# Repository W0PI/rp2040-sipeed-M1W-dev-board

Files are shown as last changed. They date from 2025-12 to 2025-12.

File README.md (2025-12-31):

# rp2040-sipeed-M1W-dev-board

*the names of the PCB files are different cause at the very start i sightly chnaged what i was doing and didnt know how to change kicad project names*

a rp2040 and a sippeed M1W on one board both connected by uart the M1W has a camera and lcd connector aswell as 8 mics in a circle for directional detection

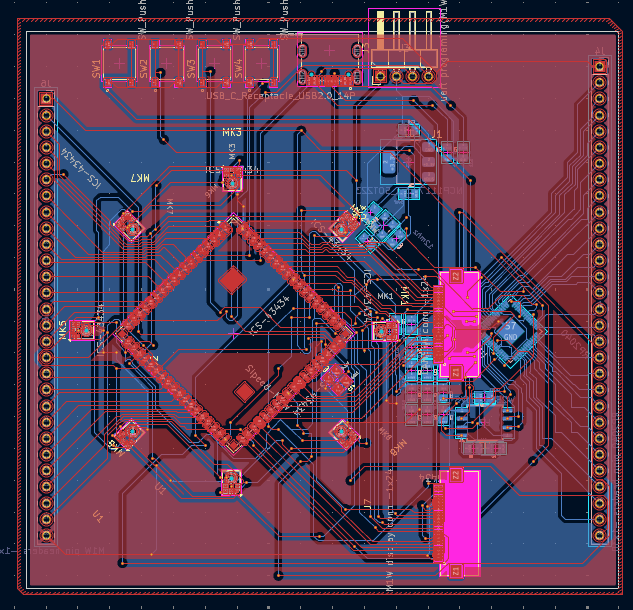
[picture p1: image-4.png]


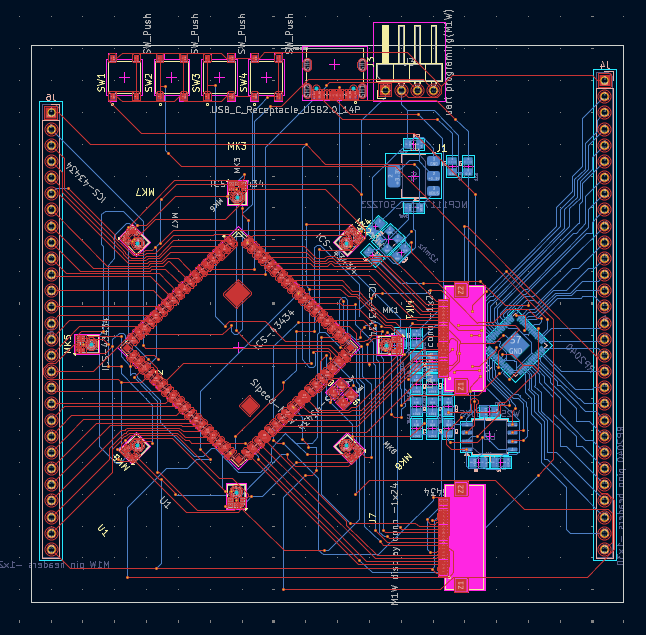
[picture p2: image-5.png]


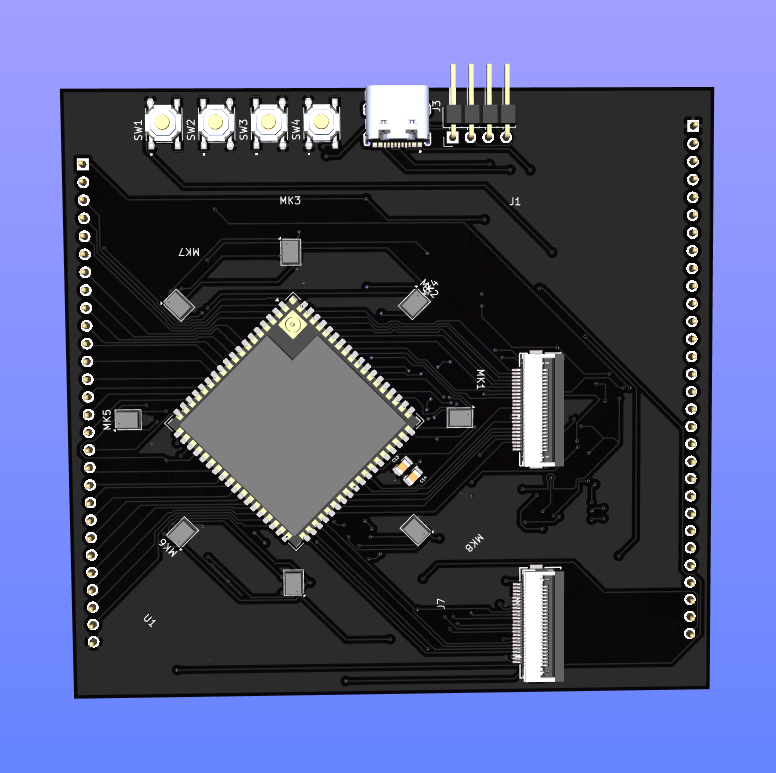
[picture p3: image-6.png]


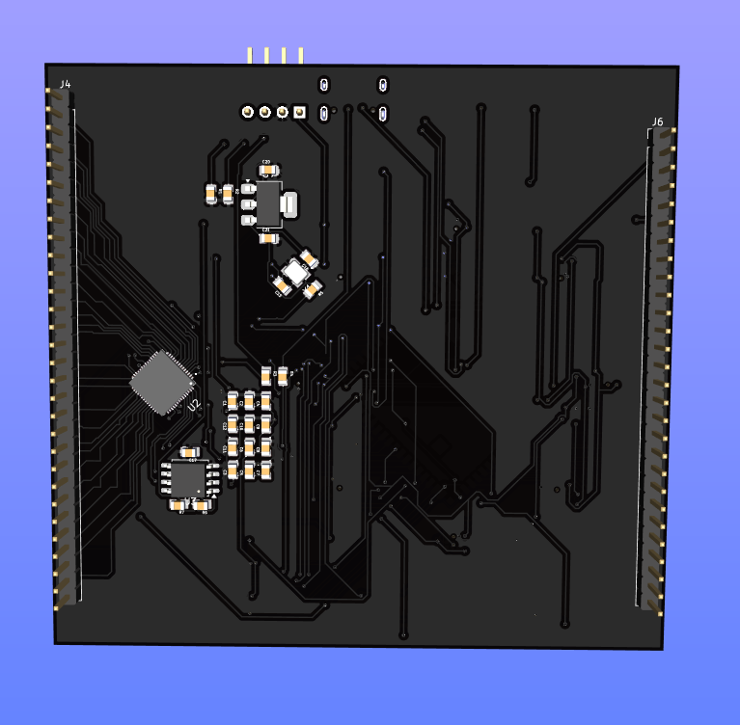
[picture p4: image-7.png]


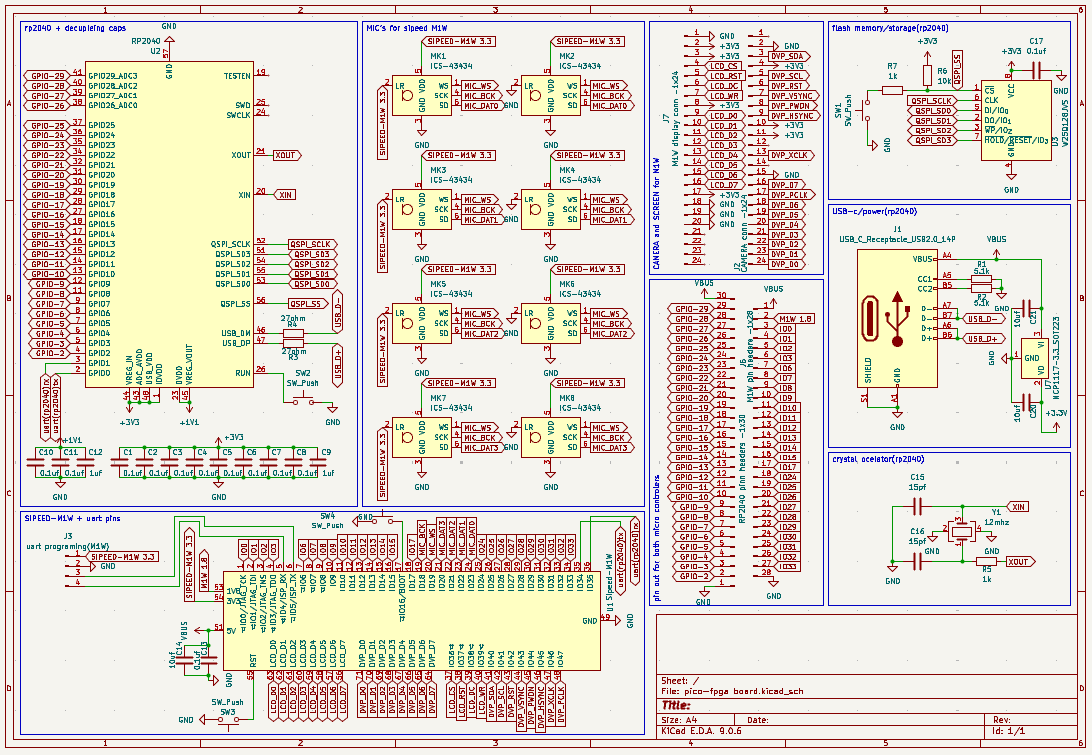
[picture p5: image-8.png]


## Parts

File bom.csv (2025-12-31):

Designator | Footprint | Quantity | Value | LCSC Part #
C1, C10, C11, C13, C17, C2, C3, C4, C5, C6, C7, C8 | 0805 | 12 | 0.1uf
C12, C9 | 0805 | 2 | 1uf
C14, C20, C21 | 0805 | 3 | 10uf
C15, C16 | 0805 | 2 | 15pf
J1 | USB-C | 1 | USB_C_Receptacle_USB2.0_14P
J2 | CAMERA conn | 1 | CAMERA conn -1x24
J3 | PinHeader_1x04_P2.54mm_Horizontal | 1 | uart programing(M1W)
J4 | PinHeader_1x30_P2.54mm_Vertical | 1 | RP2040 pinn headers -1x30
J6 | PinHeader_1x28_P2.54mm_Vertical | 1 | M1W pin headers -1x28
J7 | CAMERA conn | 1 | M1W display conn -1x24
MK1, MK2, MK3, MK4, MK5, MK6, MK7, MK8 | InvenSense_ICS-43434-6_3.5x2.65mm | 8 | ICS-43434
R1, R2 | 0805 | 2 | 5.1k
R3, R4 | 0805 | 2 | 27ohm
R5, R7 | 0805 | 2 | 1k
R6 | 0805 | 1 | 10k
SW1, SW2, SW3, SW4 | button | 4 | SW_Push
U1 | Sipeed-M1W | 1 | Sipeed-M1W
U2 | RP2040 | 1 | RP2040
U3 | SOIC-8_5.3x5.3mm_P1.27mm | 1 | W25Q128JVS
U7 | SOT-223-3_TabPin2 | 1 | NCP1117-3.3_SOT223
Y1 | 12mhz crystal | 1 | 12mhz

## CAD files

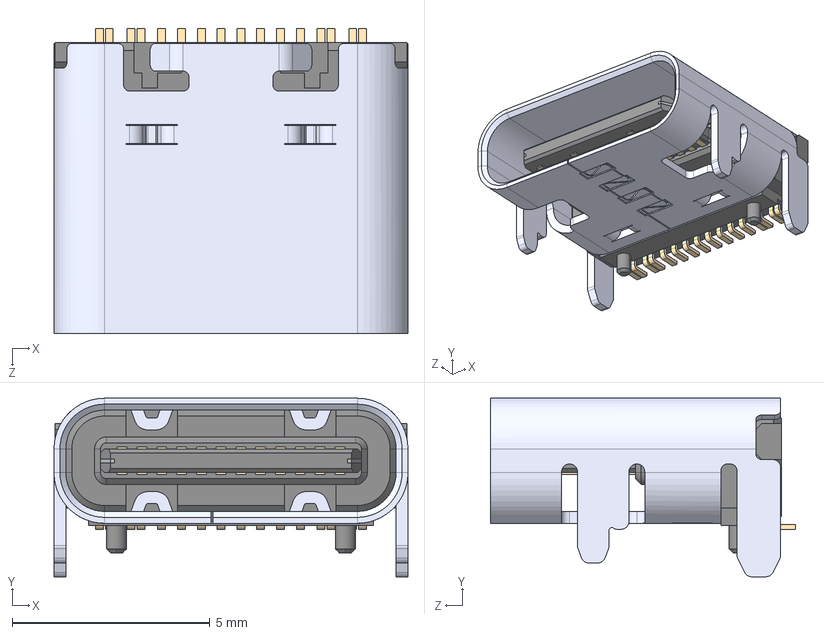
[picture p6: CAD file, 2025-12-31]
KICAD PCB files/extra 3d models/USB-C.STEP
8.94 x 4.51 x 7.71 mm

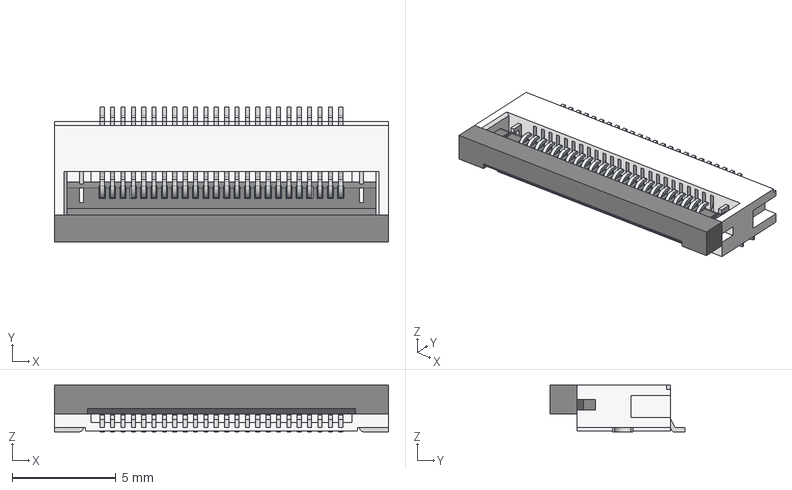
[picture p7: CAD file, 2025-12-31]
KICAD PCB files/extra 3d models/CAMERA conn.step
16.1 x 6.50 x 2.25 mm
6871xx149022_Pin x 24
6871xx149022_Patte
6871xx149022_Patte2
687124149022_Actuator

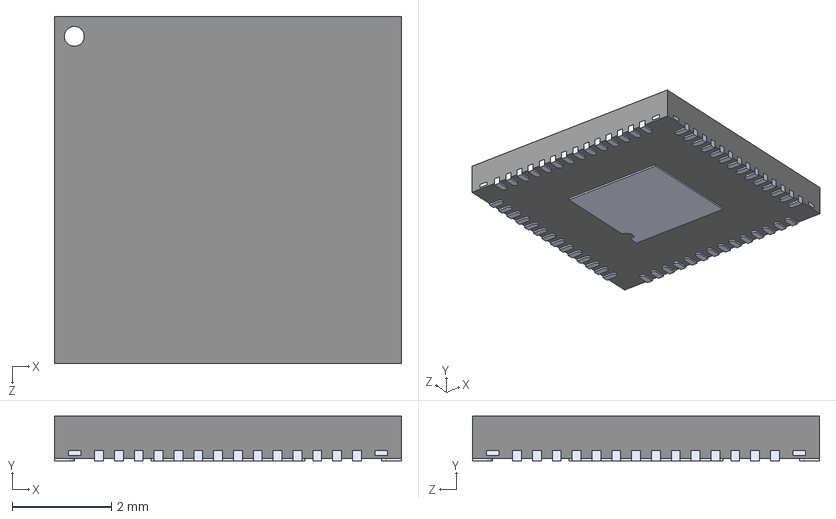
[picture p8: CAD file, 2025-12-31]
KICAD PCB files/extra 3d models/RP2040.step
7.00 x 0.9 x 7.00 mm

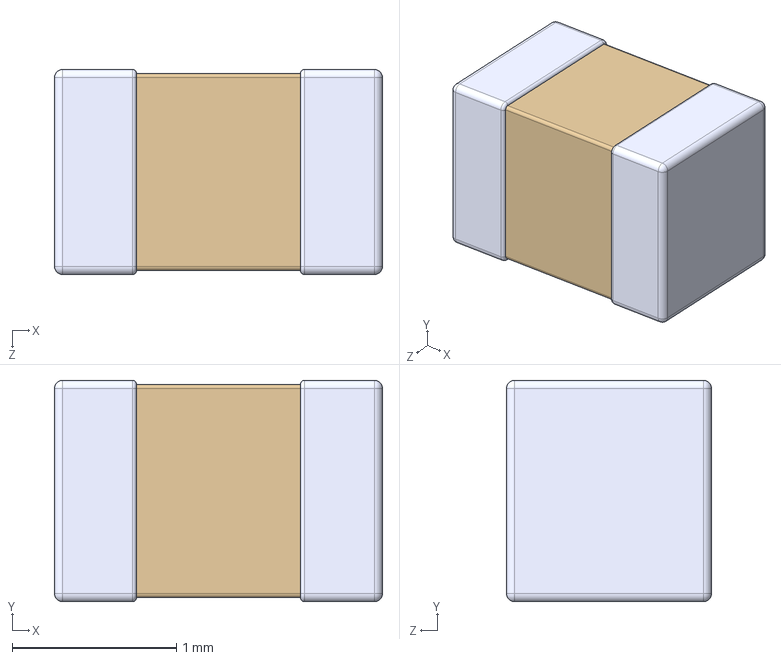
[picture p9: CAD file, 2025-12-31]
KICAD PCB files/extra 3d models/0805.step
2.00 x 1.35 x 1.25 mm

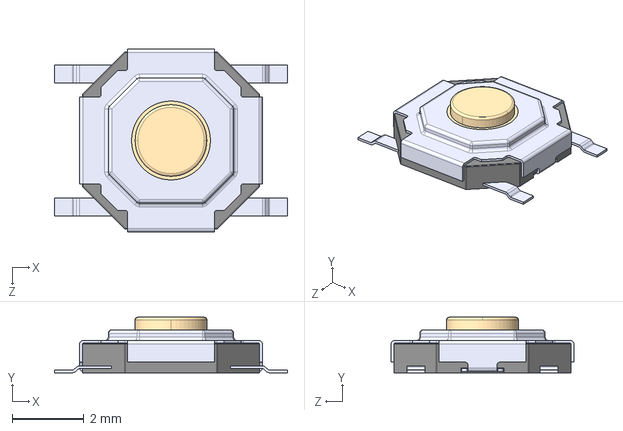
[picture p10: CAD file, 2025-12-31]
KICAD PCB files/extra 3d models/button.step
6.50 x 1.55 x 5.10 mm

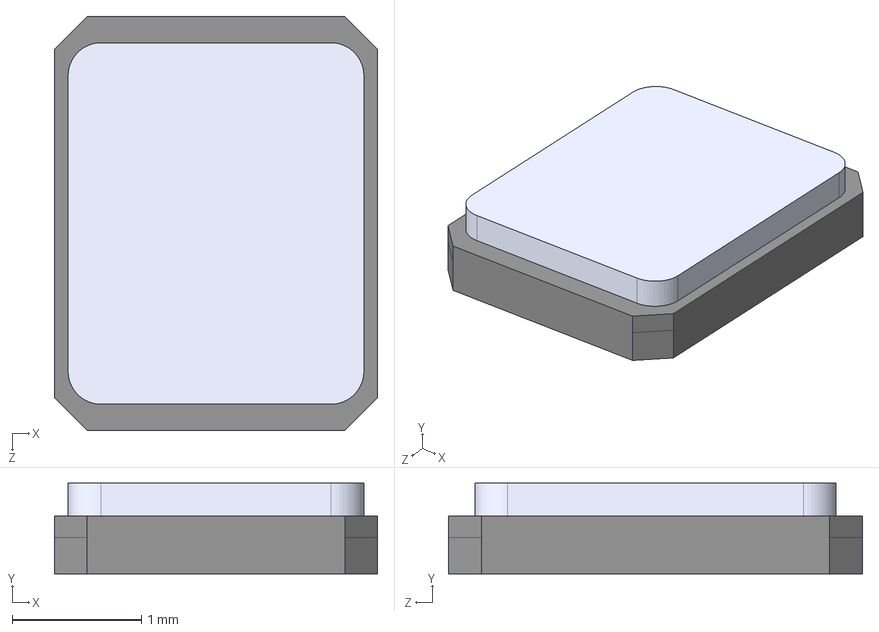
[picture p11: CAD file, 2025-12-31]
KICAD PCB files/extra 3d models/12mhz crystal.STEP
2.50 x 0.7 x 3.20 mm

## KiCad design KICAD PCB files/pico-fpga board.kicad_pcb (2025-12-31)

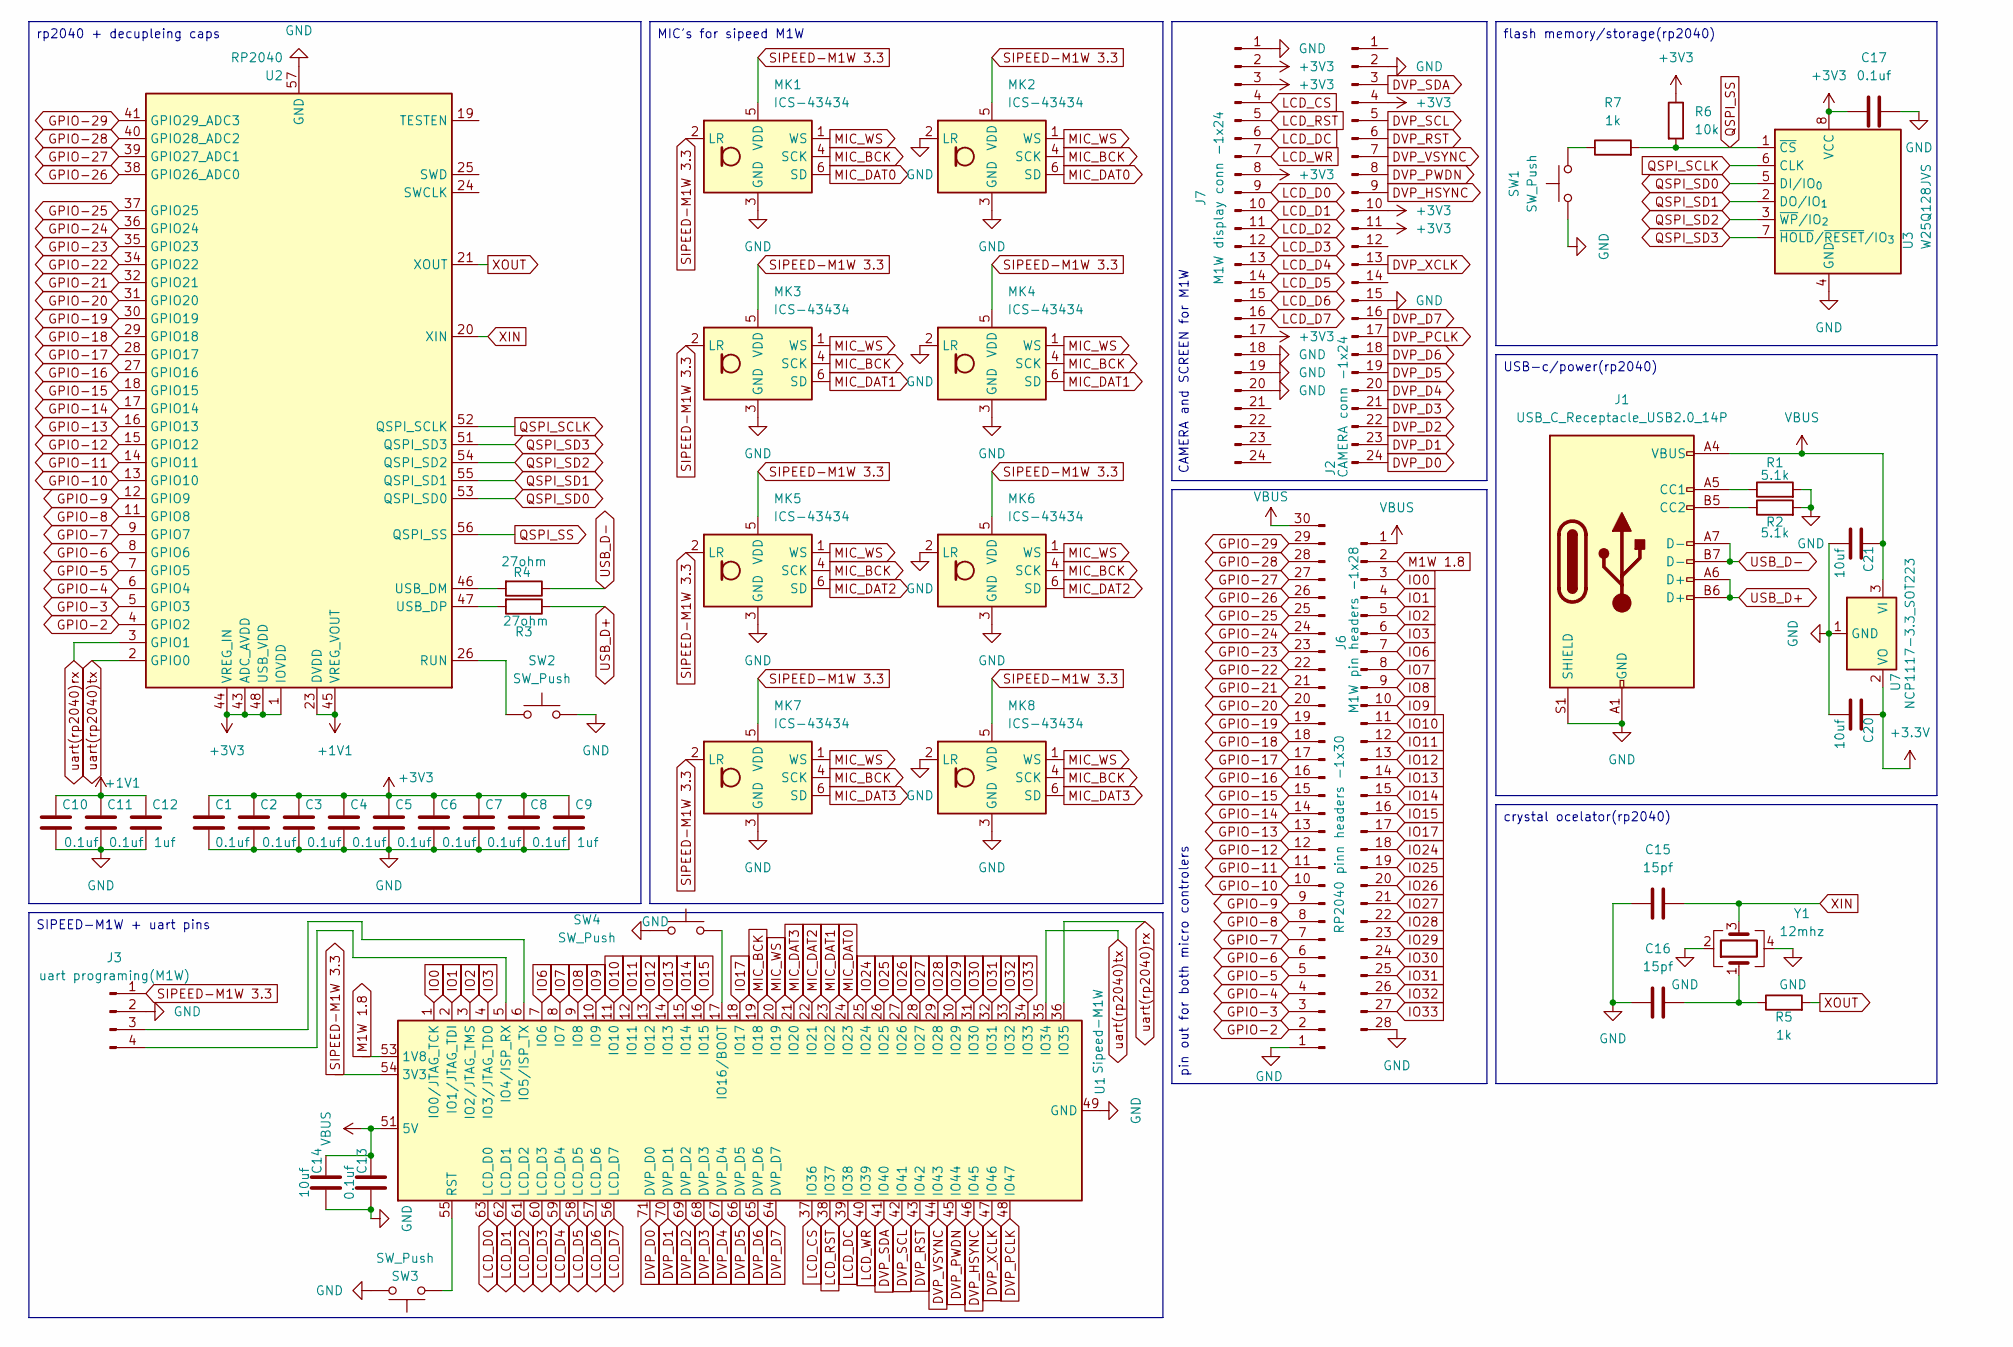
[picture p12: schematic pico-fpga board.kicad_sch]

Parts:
C1, C2, C3, C4, C5, C6, C7, C8, C10, C11, C13, C17: 0.1uf; 0805
C9, C12: 1uf; 0805
C14, C20, C21: 10uf; 0805
C15, C16: 15pf; 0805
J1: USB_C_Receptacle_USB2.0_14P; USB-C
J2: CAMERA conn -1x24; CAMERA conn
J3: uart programing(M1W); PinHeader_1x04_P2.54mm_Horizontal
J4: RP2040 pinn headers -1x30; PinHeader_1x30_P2.54mm_Vertical
J6: M1W pin headers -1x28; PinHeader_1x28_P2.54mm_Vertical
J7: M1W display conn -1x24; CAMERA conn
MK1, MK2, MK3, MK4, MK5, MK6, MK7, MK8: ICS-43434; InvenSense_ICS-43434-6_3.5x2.65mm
R1, R2: 5.1k; 0805
R3, R4: 27ohm; 0805
R5, R7: 1k; 0805
R6: 10k; 0805
SW1, SW2, SW3, SW4: SW_Push; button
U1: Sipeed-M1W
U2: RP2040; QFN-56-1EP_7x7mm_P0.4mm_EP3.2x3.2mm
U3: W25Q128JVS; SOIC-8_5.3x5.3mm_P1.27mm
U7: NCP1117-3.3_SOT223; SOT-223-3_TabPin2
Y1: 12mhz; 12mhz crystal

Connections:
+1V1: C10.1, C11.1, C12.1, U2.23 (DVDD), U2.45 (VREG_VOUT), U2.50 (DVDD)
+3.3V: C20.1, U7.2 (VO)
+3V3: C1.1, C2.1, C3.1, C4.1, C5.1, C6.1, C7.1, C8.1, C9.1, C17.1, J2.4, J2.10, J2.11, J7.2, J7.3, J7.8, J7.17, R6.1, U2.1 (IOVDD), U2.10 (IOVDD), U2.22 (IOVDD), U2.33 (IOVDD), U2.42 (IOVDD), U2.43 (ADC_AVDD), U2.44 (VREG_IN), U2.48 (USB_VDD), U2.49 (IOVDD), U3.8 (VCC)
DVP_D0: J2.24, U1.71 (DVP_D0)
DVP_D1: J2.23, U1.70 (DVP_D1)
DVP_D2: J2.22, U1.69 (DVP_D2)
DVP_D3: J2.21, U1.68 (DVP_D3)
DVP_D4: J2.20, U1.67 (DVP_D4)
DVP_D5: J2.19, U1.66 (DVP_D5)
DVP_D6: J2.18, U1.65 (DVP_D6)
DVP_D7: J2.16, U1.64 (DVP_D7)
DVP_HSYNC: J2.9, U1.46 (IO45)
DVP_PCLK: J2.17, U1.48 (IO47)
DVP_PWDN: J2.8, U1.45 (IO44)
DVP_RST: J2.6, U1.43 (IO42)
DVP_SCL: J2.5, U1.42 (IO41)
DVP_SDA: J2.3, U1.41 (IO40)
DVP_VSYNC: J2.7, U1.44 (IO43)
DVP_XCLK: J2.13, U1.47 (IO46)
GND: C1.2, C2.2, C3.2, C4.2, C5.2, C6.2, C7.2, C8.2, C9.2, C10.2, C11.2, C12.2, C13.1, C14.1, C15.1, C16.1, C17.2, C20.2, C21.2, J1.A1 (GND), J1.A12 (GND), J1.B1 (GND), J1.B12 (GND), J1.S1 (SHIELD), J2.2, J2.15, J3.2, J4.1, J6.28, J7.1, J7.18, J7.19, J7.20, MK1.3 (GND), MK2.2 (LR), MK2.3 (GND), MK3.3 (GND), MK4.2 (LR), MK4.3 (GND), MK5.3 (GND), MK6.2 (LR), MK6.3 (GND), MK7.3 (GND), MK8.2 (LR), MK8.3 (GND), R1.2, R2.2, SW1.1, SW2.2, SW3.2, SW4.1, U1.49 (GND), U1.50 (GND), U1.72 (GND), U2.57 (GND), U3.4 (GND), U7.1 (GND), Y1.2, Y1.4
GPIO-2: J4.2, U2.4 (GPIO2)
GPIO-3: J4.3, U2.5 (GPIO3)
GPIO-4: J4.4, U2.6 (GPIO4)
GPIO-5: J4.5, U2.7 (GPIO5)
GPIO-6: J4.6, U2.8 (GPIO6)
GPIO-7: J4.7, U2.9 (GPIO7)
GPIO-8: J4.8, U2.11 (GPIO8)
GPIO-9: J4.9, U2.12 (GPIO9)
GPIO-10: J4.10, U2.13 (GPIO10)
GPIO-11: J4.11, U2.14 (GPIO11)
GPIO-12: J4.12, U2.15 (GPIO12)
GPIO-13: J4.13, U2.16 (GPIO13)
GPIO-14: J4.14, U2.17 (GPIO14)
GPIO-15: J4.15, U2.18 (GPIO15)
GPIO-16: J4.16, U2.27 (GPIO16)
GPIO-17: J4.17, U2.28 (GPIO17)
GPIO-18: J4.18, U2.29 (GPIO18)
GPIO-19: J4.19, U2.30 (GPIO19)
GPIO-20: J4.20, U2.31 (GPIO20)
GPIO-21: J4.21, U2.32 (GPIO21)
GPIO-22: J4.22, U2.34 (GPIO22)
GPIO-23: J4.23, U2.35 (GPIO23)
GPIO-24: J4.24, U2.36 (GPIO24)
GPIO-25: J4.25, U2.37 (GPIO25)
GPIO-26: J4.26, U2.38 (GPIO26_ADC0)
GPIO-27: J4.27, U2.39 (GPIO27_ADC1)
GPIO-28: J4.28, U2.40 (GPIO28_ADC2)
GPIO-29: J4.29, U2.41 (GPIO29_ADC3)
IO0: J6.3, U1.1 (IO0/JTAG_TCK)
IO1: J6.4, U1.2 (IO1/JTAG_TDI)
IO2: J6.5, U1.3 (IO2/JTAG_TMS)
IO3: J6.6, U1.4 (IO3/JTAG_TDO)
IO6: J6.7, U1.7 (IO6)
IO7: J6.8, U1.8 (IO7)
IO8: J6.9, U1.9 (IO8)
IO9: J6.10, U1.10 (IO9)
IO10: J6.11, U1.11 (IO10)
IO11: J6.12, U1.12 (IO11)
IO12: J6.13, U1.13 (IO12)
IO13: J6.14, U1.14 (IO13)
IO14: J6.15, U1.15 (IO14)
IO15: J6.16, U1.16 (IO15)
IO17: J6.17, U1.18 (IO17)
IO24: J6.18, U1.25 (IO24)
IO25: J6.19, U1.26 (IO25)
IO26: J6.20, U1.27 (IO26)
IO27: J6.21, U1.28 (IO27)
IO28: J6.22, U1.29 (IO28)
IO29: J6.23, U1.30 (IO29)
IO30: J6.24, U1.31 (IO30)
IO31: J6.25, U1.32 (IO31)
IO32: J6.26, U1.33 (IO32)
IO33: J6.27, U1.34 (IO33)
LCD_CS: J7.4, U1.37 (IO36)
LCD_D0: J7.9, U1.63 (LCD_D0)
LCD_D1: J7.10, U1.62 (LCD_D1)
LCD_D2: J7.11, U1.61 (LCD_D2)
LCD_D3: J7.12, U1.60 (LCD_D3)
LCD_D4: J7.13, U1.59 (LCD_D4)
LCD_D5: J7.14, U1.58 (LCD_D5)
LCD_D6: J7.15, U1.57 (LCD_D6)
LCD_D7: J7.16, U1.56 (LCD_D7)
LCD_DC: J7.6, U1.39 (IO38)
LCD_RST: J7.5, U1.38 (IO37)
LCD_WR: J7.7, U1.40 (IO39)
M1W 1.8: J6.2, U1.53 (1V8)
MIC_BCK: MK1.4 (SCK), MK2.4 (SCK), MK3.4 (SCK), MK4.4 (SCK), MK5.4 (SCK), MK6.4 (SCK), MK7.4 (SCK), MK8.4 (SCK), U1.19 (IO18)
MIC_DAT0: MK1.6 (SD), MK2.6 (SD), U1.24 (IO23)
MIC_DAT1: MK3.6 (SD), MK4.6 (SD), U1.23 (IO22)
MIC_DAT2: MK5.6 (SD), MK6.6 (SD), U1.22 (IO21)
MIC_DAT3: MK7.6 (SD), MK8.6 (SD), U1.21 (IO20)
MIC_WS: MK1.1 (WS), MK2.1 (WS), MK3.1 (WS), MK4.1 (WS), MK5.1 (WS), MK6.1 (WS), MK7.1 (WS), MK8.1 (WS), U1.20 (IO19)
unnamed: C16.2, R5.1, Y1.1
unnamed: J1.A5 (CC1), R1.1
unnamed: J1.B5 (CC2), R2.1
unnamed: J3.3, U1.6 (IO5/ISP_TX)
unnamed: J3.4, U1.5 (IO4/ISP_RX)
unnamed: R7.1, SW1.2
unnamed: SW4.2, U1.17 (IO16/BOOT)
unnamed: SW3.1, U1.55 (RST)
unnamed: SW2.1, U2.26 (RUN)
unnamed: R4.2, U2.46 (USB_DM)
unnamed: R3.2, U2.47 (USB_DP)
QSPI_SCLK: U2.52 (QSPI_SCLK), U3.6 (CLK)
QSPI_SD0: U2.53 (QSPI_SD0), U3.5 (DI/IO_{0})
QSPI_SD1: U2.55 (QSPI_SD1), U3.2 (DO/IO_{1})
QSPI_SD2: U2.54 (QSPI_SD2), U3.3 (~WP/IO_{2})
QSPI_SD3: U2.51 (QSPI_SD3), U3.7 (~HOLD/~RESET/IO_{3})
QSPI_SS: R6.2, R7.2, U2.56 (QSPI_SS), U3.1 (~CS)
SIPEED-M1W 3.3: J3.1, MK1.2 (LR), MK1.5 (VDD), MK2.5 (VDD), MK3.2 (LR), MK3.5 (VDD), MK4.5 (VDD), MK5.2 (LR), MK5.5 (VDD), MK6.5 (VDD), MK7.2 (LR), MK7.5 (VDD), MK8.5 (VDD), U1.54 (3V3)
USB_D+: J1.A6 (D+), J1.B6 (D+), R3.1
USB_D-: J1.A7 (D-), J1.B7 (D-), R4.1
VBUS: C13.2, C14.2, C21.1, J1.A4 (VBUS), J1.A9 (VBUS), J1.B4 (VBUS), J1.B9 (VBUS), J4.30, J6.1, U1.51 (5V), U1.52 (5V), U7.3 (VI)
XIN: C15.2, U2.20 (XIN), Y1.3
XOUT: R5.2, U2.21 (XOUT)
uart(rp2040)rx: U1.36 (IO35), U2.3 (GPIO1)
uart(rp2040)tx: U1.35 (IO34), U2.2 (GPIO0)

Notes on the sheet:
MIC's for sipeed M1W
flash memory/storage(rp2040)
pin out for both micro controlers
SIPEED-M1W + uart pins
crystal ocelator(rp2040)
rp2040 + decupleing caps
CAMERA and SCREEN for M1W
USB-c/power(rp2040)

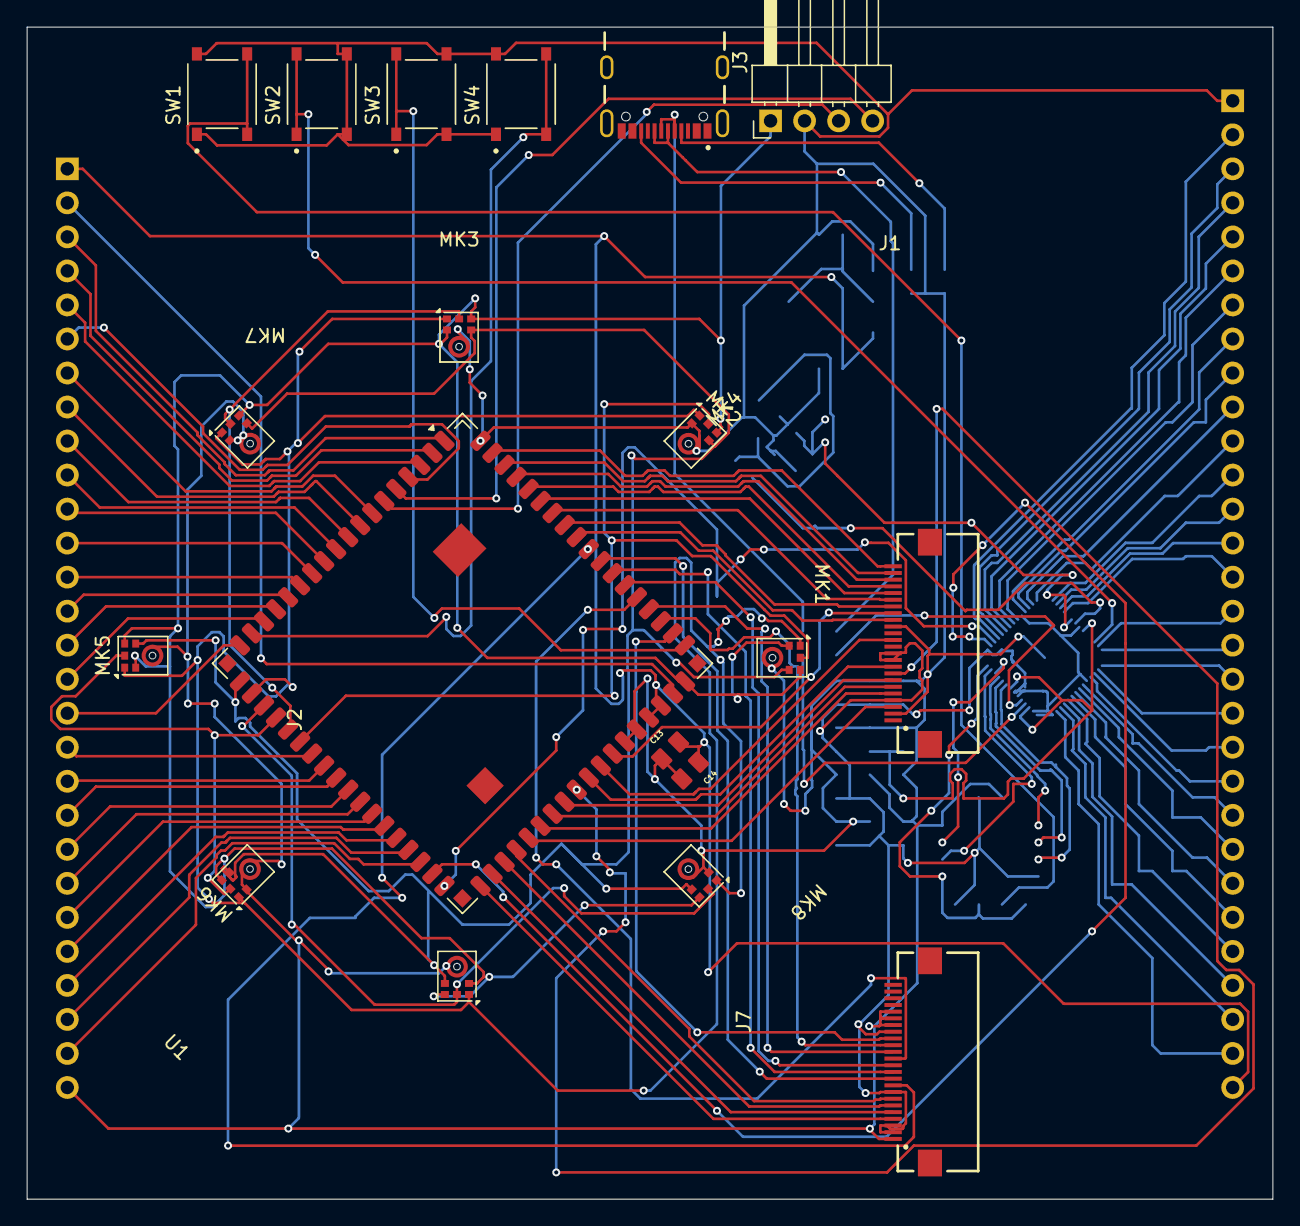
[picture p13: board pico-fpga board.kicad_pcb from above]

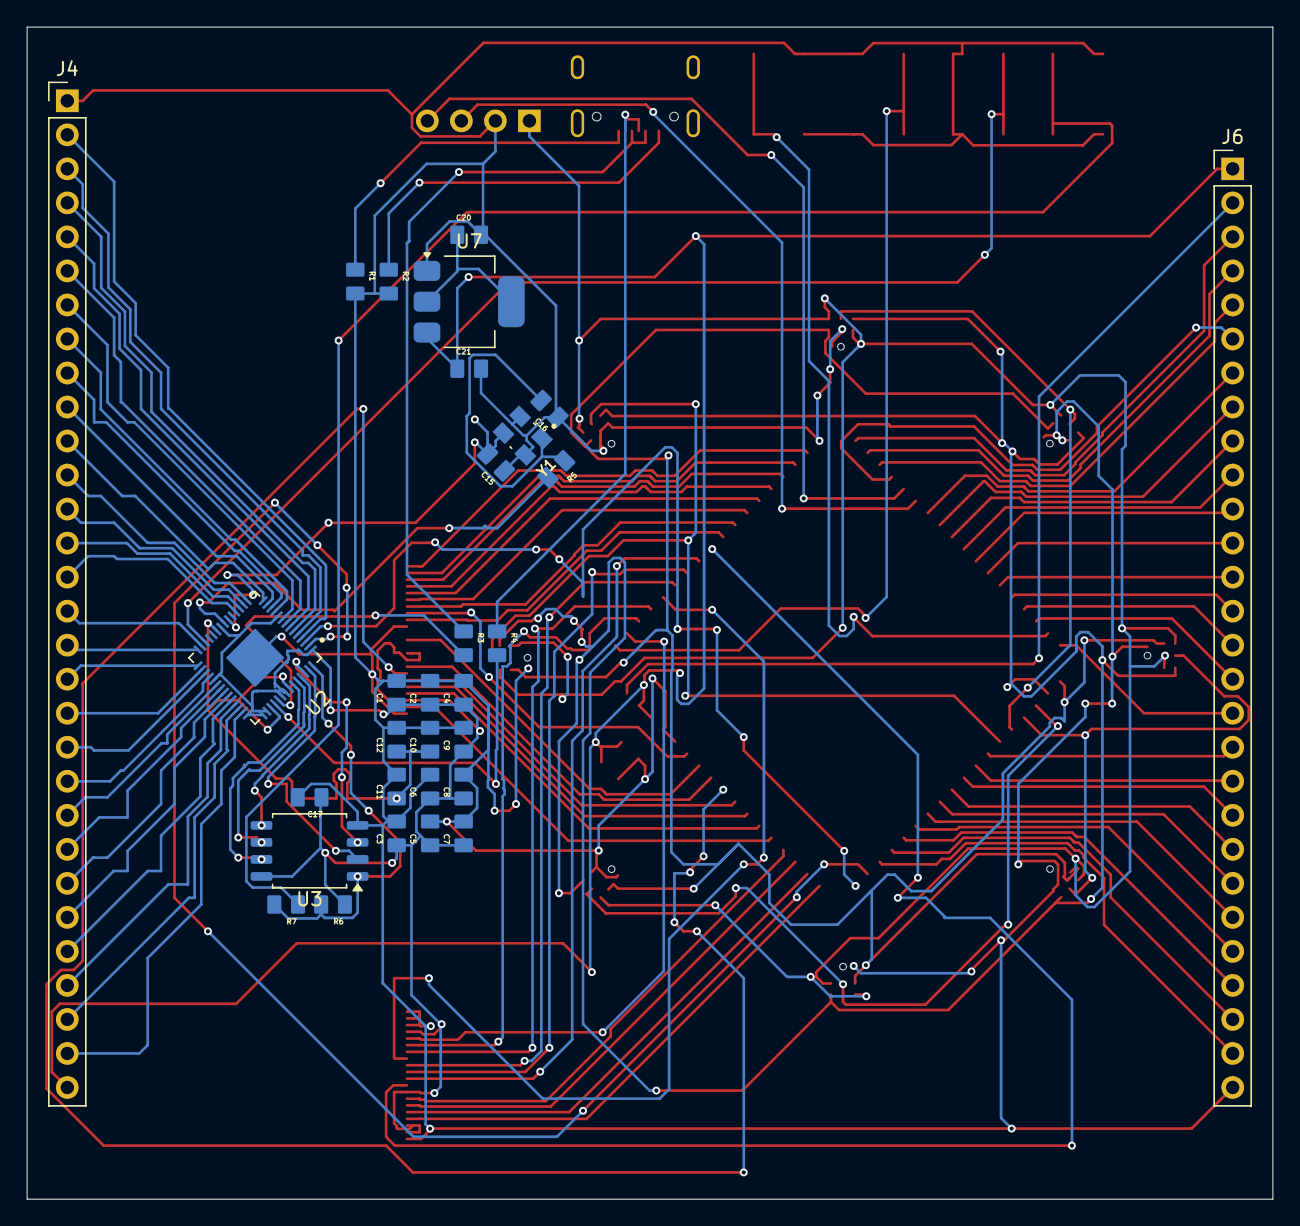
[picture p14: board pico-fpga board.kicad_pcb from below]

Board: 2 copper layers, 93.0 x 87.5 mm, 49 parts (30 on the bottom side), 117 nets.
